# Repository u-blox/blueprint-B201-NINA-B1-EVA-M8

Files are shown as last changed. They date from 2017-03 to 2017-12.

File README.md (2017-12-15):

# blueprint-B201-NINA-B1-EVA-M8
This blueprint is a small solar powered location device with the NINA-B1 Bluetooth Low Energy and the EVA-M8 GNSS modules from u-blox.

* Provides a reference for integration of u-blox BLE and GNSS modules for location applications.
* Implements a low power solution integrating a harvesting power system.
* Gives an example of components choice, placement, and layout.

A demo firmware is available that can be used to test features of the blueprint. The firmware collects location data and provides this data via the standardized Bluetooth Low Energy GATT Location and Navigation Service.

## Disclaimer
Copyright (C) u-blox 

u-blox reserves all rights in this deliverable (documentation, software, etc.,
hereafter “Deliverable”). 

u-blox grants you the right to use, copy, modify and distribute the
Deliverable provided hereunder for any purpose without fee.

THIS DELIVERABLE IS BEING PROVIDED "AS IS", WITHOUT ANY EXPRESS OR IMPLIED
WARRANTY. IN PARTICULAR, NEITHER THE AUTHOR NOR U-BLOX MAKES ANY
REPRESENTATION OR WARRANTY OF ANY KIND CONCERNING THE MERCHANTABILITY OF THIS
DELIVERABLE OR ITS FITNESS FOR ANY PARTICULAR PURPOSE.

In case you provide us a feedback or make a contribution in the form of a
further development of the Deliverable (“Contribution”), u-blox will have the
same rights as granted to you, namely to use, copy, modify and distribute the
Contribution provided to us for any purpose without fee.

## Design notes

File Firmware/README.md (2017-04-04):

# B201 Location demo software

## General behavior

* Position, fix status, UTC time  and data valid are read from the NMEA message $xxRMC
* If fix status is ok and data are valid the position and time are presented in the standardized GATT Service ”Location and Navigation”
* If a remote device subscribes to GATT notifications these will be sent for every $xxRMC message NINA-B1 receives from the GNSS module
* When switching off the device with the ON/OFF button NINA-B1 will switch off the power to the GNSS module before entering sleep mode
* The device will automatically switch off if inactive for more than 3 min
* LED1 will indicate device running (0.2/1.8s) as well as any active BLE connection (0.4/4.0s)

## Program the device

Precompiled firmware is provided and can be used with B201 hardware. The .hex file is available in the ```/hex``` folder.   
**Please note!** This firmware requires SoftDevice s132_nrf52_3.0.0 to be programmed to the device.

## Compile the software

* Clone this repository   
```> git clone https://github.com/u-blox/blueprint-B201-NINA-B1-EVA-M8```

* Download the source code for nRF5 SDK version 12.2.0 from [Nordic](https://www.nordicsemi.com/eng/nordic/Products/nRF5-SDK/nRF5-SDK-v12-zip/54291)

* Copy ```custom_board.h``` to the ```/components/boards``` folder of the SDK

* Update the SDK_ROOT variable in the Makefile according to your installation of the nRF5 SDK   
```For example: SDK_ROOT := C:/nRF5_SDK_12.2.0```

* Go to the project directory (where the Makefile is located) and execute the ```make``` command

* The generated software (ninab1.hex) is located in the ```/_build``` folder

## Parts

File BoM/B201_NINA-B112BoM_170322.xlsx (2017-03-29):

Part Number | Part Reference | Quantity | Value | Description | Manufacturer | Manufacturer Part Number | Distributor | Distributor Part Number
TMP-143 | ANT2 | 1 | MWSL1203D | GPS Helix Antenna on SMA | Maruwa | MWSL1203D
TMP-112 | C1 C5 C8 C9 C13 C15 C16 C17 C19 C113 | 10 | 100n | MLCC0201 100nF 10V X5R 10% | TDK | C0603X5R1A104K030BC | Digi-Key | 445-7318-1-ND
TMP-165 | C6 C7 C10 C11 C12 | 5 | 10u | MLCC0805 10uF 10V X7R 10% | Murata | GRM21BR71A106KE51L | Digi-Key | 490-3905-6-ND
TMP-119 | C14 | 1 | 10n | MLCC0201 10nF 10V X7R 10% | TDK | C0603X7R1A103K030BA | Digi-Key | 445-6843-1-ND
TMP-113 | C18 | 1 | 1n | MLCC0201 1nF 25V X7R 10% | TDK | C0603X5R1E102K030BA | Digi-Key | 445-1790-1-ND
TMP-54 | C23 C24 | 2 | 1u | MLCC0603 1uF 16V X7R 10% | TDK | C1608X7R1C105K080AC | Digi-Key | 445-1604-2-ND
TMP-42 | D1 D4 D5 | 3 | LED Green | LED Green Clear 0603 SMD | Lite-On | LTST-C190KGKT | Digi-Key | 160-1435-6-ND
TMP-148 | FIL1 | 1 | B8813 | SAW Filter for GPS, COMPASS, GLONASS | TDK | B39162B8813P810 | Digikey | 495-7022-1-ND
TMP-132 | J1 | 1 | Header_2x5 | Header 2x5, p 1mm | Sullins | SFM210-LPSE-D05-SP-BK | Digi-Key | S9268-ND
TMP-137 | J2 | 1 | CP1454-A3-ST | Li-Ion battery 85mAh | Varta | CP1454-A3-ST | Weisbauer Elektronik
TMP-189 | J4 | 1 | SMA (F) edge | SMA (F) Jack for edge PCB mount, 1.6mm thickness | Samtec | SMA-J-P-H-ST-EM1 | Digi-Key | SAM8857-ND
TMP-139 | J9 | 1 | 0473460001 | micro USB conn SMT, RA | Molex | 0473460001 | Digi-Key | WM17141CT-ND
TMP-122 | L1 | 1 | 22u | Inductor 22uH 30% 450mohm, 360mA | Wurth | 744031220 | Digi-Key | 732-1012-2-ND
TMP-61 | L2 | 1 | 2u2 | Inductor 2,2uH 20% 110mohm, 1,2A | TDK | MLP2016H2R2MT0S1 | Digi-Key | 445-15724-1-ND
TMP-114 | L3 | 1 | 6n2 | Inductor 6,2nH +/-0.1nH 700mA | Murata | LQW15AN6N2B00D | Digi-Key | 490-6838-1-ND
TMP-149 | PCB1 | 1 | UBX-xxxxxx | NINA-B1, Blueprint B201 | u-blox | UBX-xxxxxx
TMP-130 | Q1 Q2 Q3 Q4 | 4 | CSD17381F4 | N-ch mosfet, 30V 3,1A | TI | CSD17381F4 | Digi-Key | 296-38913-1-ND
TMP-191 | R1 R2 | 2 | 18K | Thick-Film 18K 0201 1% | Rohm | MCR006YZPF1802 | Digi-Key | RHM18KABCT-ND
TMP-28 | R3 R58 | 2 | 470R | Thick-Film 470R 0402 5% | Rohm | MCR01MRTJ471 | Digi-Key | RHM470CECT-ND
TMP-134 | R4 | 1 | 330 | Thick-Film 330 0201 5% | Rohm | MCR006YRTJ331 | Digi-Key | RHM330CCCT-ND
TMP-135 | R5 R6 R12 R18 R59 | 5 | 100k | Thick-Film 100k 0201 1% | Rohm | MCR006YRTF1003 | Digi-Key | RHM100KCBCT-ND
TMP-133 | R7 R20 | 2 | 2K2 | Thick-Film 2K2 0201 1% | Rohm | MCR006YRTF2201 | Digi-Key | RHM2.2KCBCT-ND
TMP-123 | R8 R11 R16 | 3 | 5M49 | Thick-Film 5M49 0603 1% | Vishay | CRCW06035M49FKEA | Digi-Key | 541-5.49MHCT-ND
TMP-128 | R9 | 1 | 620k | Thick-Film 620k 0603 1% | Vishay | CRCW0603620KFKEA | Digi-Key | 541-620KHCT-ND
TMP-126 | R10 | 1 | 2M43 | Thick-Film 2M43 0603 1% | Vishay | CRCW06032M43FKEA | Digi-Key | 541-2.43MHCT-ND
TMP-127 | R13 R15 | 2 | 4M42 | Thick-Film 4M42 0603 1% | Vishay | CRCW06034M42FKEA | Digi-Key | 541-4.42MHCT-ND
TMP-125 | R14 | 1 | 9M31 | Thick-Film 9M31 0603 1% | Vishay | CRCW06039M31FKEA | Digi-Key | 541-9.31MHCT-ND
TMP-124 | R17 | 1 | 3M92 | Thick-Film 3M92 0603 1% | Vishay | CRCW06033M92FKEA | Digi-Key | 541-3.92MHCT-ND
TMP-141 | R19 | 1 | 10K | Thick-Film 10K 0201 1% | Rohm | MCR006YRTF1002 | Digi-Key | RHM10KCBCT-ND
TMP-190 | R21 | 1 | 820 | Thick-Film 820 0201 1% | Rohm | MCR006YRTF8200 | Digi-Key | RHM820CBCT-ND
TMP-144 | R54 R60 R63 R65 | 4 | 0R | Thick-Film 0R 0201 | Rohm | MCR006YRTJ000 | Digi-Key | RHM0.0CCCT-ND
TMP-156 | R61 | 1 | 2M | Thick-Film 2M 0402 1% | Samsung | RC1005F205CS | Digi-Key | 1276-4293-1-ND
TMP-155 | R62 | 1 | 3M | Thick-Film 3M 0402 1% | Samsung | RC1005F305CS | Digi-Key | 1276-4300-1-ND
TMP-136 | SW2 SW3 SW4 | 3 | B3U-1000P | Tactile Switch, Vertical | Omron | B3U-1000P | Digi-Key | SW1020CT-ND
TMP-150 | U1 | 1 | NINA-B112 | Stand-alone Bluetooth low energy module with internal antenna | u-blox | NINA-B112-00B-00
TMP-131 | U2 | 1 | BQ29700 | V-C protection for single cell Li-Ion/Li-Po | TI | BQ29700DSER | Digi-Key | 296-43985-1-ND
TMP-121 | U3 | 1 | SLMD121H04L | Monocristalline Solar cell 44,6mA@2V | IXYS | SLMD121H04L | Digi-Key | SLMD121H04L-ND
TMP-117 | U4 | 1 | LSM6DSL | always-on 3D accelerometer and gyroscope | ST micro | LSM6DSL | Digi-Key | 497-16705-1-ND
TMP-118 | U5 | 1 | BQ25504 | Ultra Low-Power Boost Conv. w/ Batt. Mgmt for Energy Harv. Appl. | TI | BQ25504RG | Digi-Key | 296-29741-1-ND
TMP-60 | U6 | 1 | TPS62740 | TPS6274x 360nA IQ Step Down Converter For Low Power Applications | TI | TPS62740DSST | Digi-Key | 296-37134-1-ND
TMP-108 | U7 | 1 | EVA-M8M | Concurrent GNSS module, GPS+GLONASS | u-blox | EVA-M8M-0
TMP-110 | U8 | 1 | BGA825L6S | Si-Ge LNA for GNSS | Infineon | BGA825L6S | Digi-Key | BGA 825L6S E6327CT-ND
TMP-109 | U9 | 1 | MX25U1635E | 16Mbit 1.8V CMOS Serial Flash Memory | Macronix | MX25U1635EZUI-10G | Digi-Key | 1092-1057-ND
TMP-140 | U10 | 1 | BQ25101 | Single Cell Li-Ion charger with 75nA Batt Leakage | TI | BQ25101YFPR | Digi-Key | 296-39933-1-ND
TMP-154 | U12 | 1 | LPV801 | Single Nanopower Operational Amplifier | TI | LPV801DBV | Digi-Key | PLPV801DBVT-ND
TMP-115 | Y1 | 1 | 32.768KHz | 32.768KHz crystal, 7pF Cl, -40/+85, 20ppm | ECS inc. | ECS-.327-7-12-TR | Digi-Key | XC1946CT-ND

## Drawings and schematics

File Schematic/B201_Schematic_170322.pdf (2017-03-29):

# 01 - Block Diagram

# Incl.:

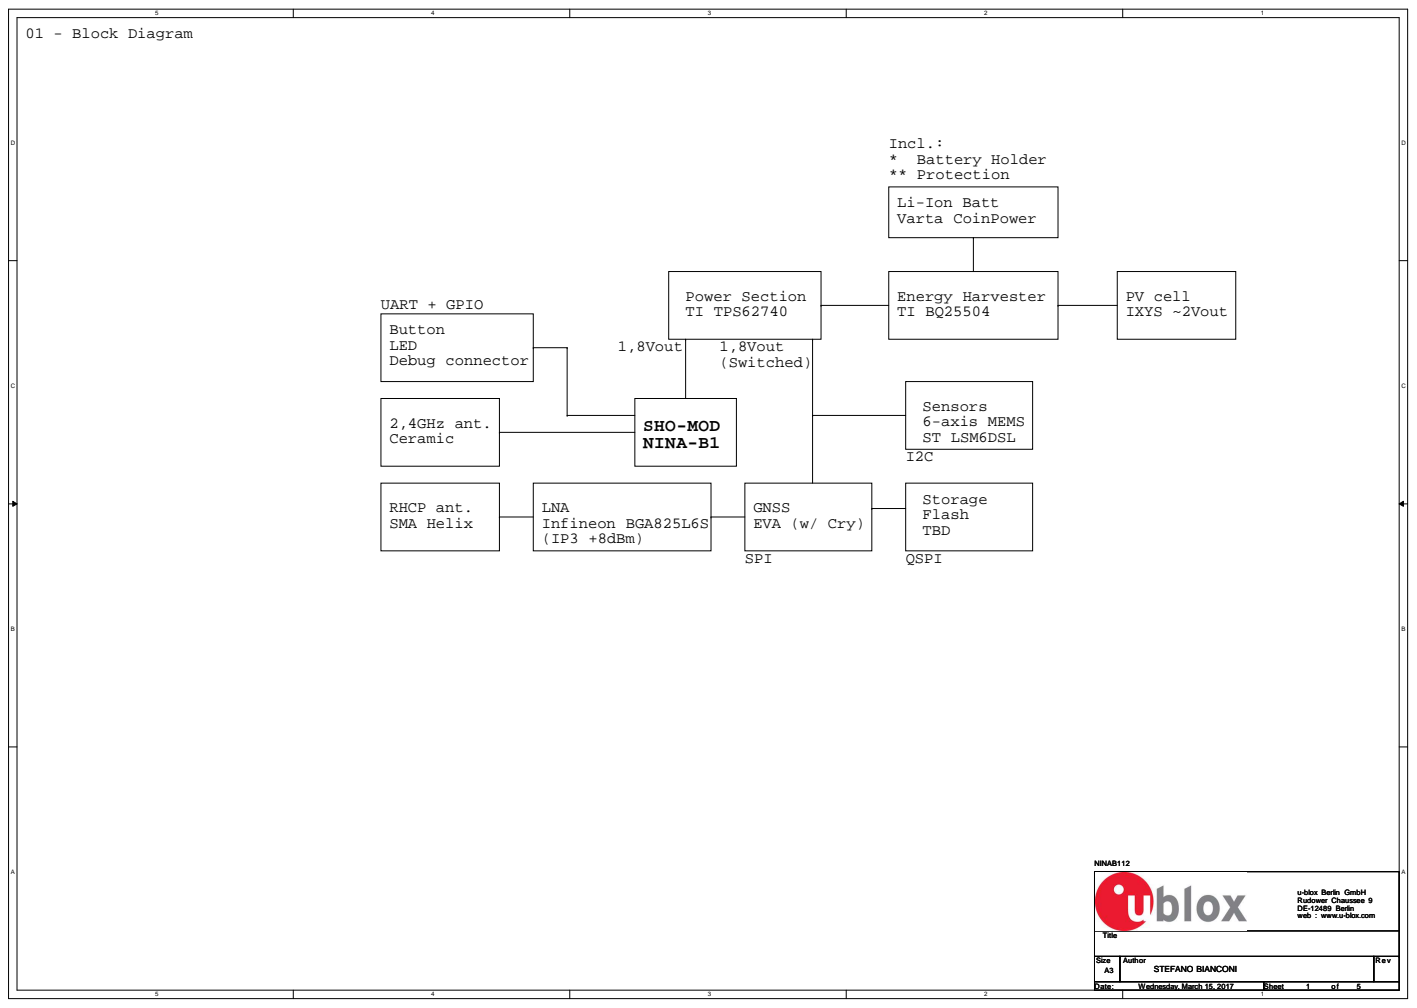
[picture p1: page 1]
PV cell IXYS ~2Vout; GNSS EVA (w/ Cry); Energy Harvester TI BQ25504; Power Section TI TPS62740; 1,8Vout; SHO-MOD NINA-B1; 1,8Vout (Switched); LNA Infineon BGA825L6S (IP3 +8dBm); RHCP ant. SMA Helix; 2,4GHz ant. Ceramic; Sensors 6-axis MEMS ST LSM6DSL; Storage Flash TBD; Button LED Debug connector; SPI; UART + GPIO; QSPI; Size; Title; Date:; Sheet; Author; STEFANO BIANCONI; Wednesday, March 15, 2017; NINAB112

* Battery Holder
** Protection
Li-Ion Batt
Varta CoinPower

u-blox Berlin GmbH
Rudower Chaussee 9
DE-12489 Berlin
web : www.u-blox.com

# Revision History

Date | Reason to Change | Description

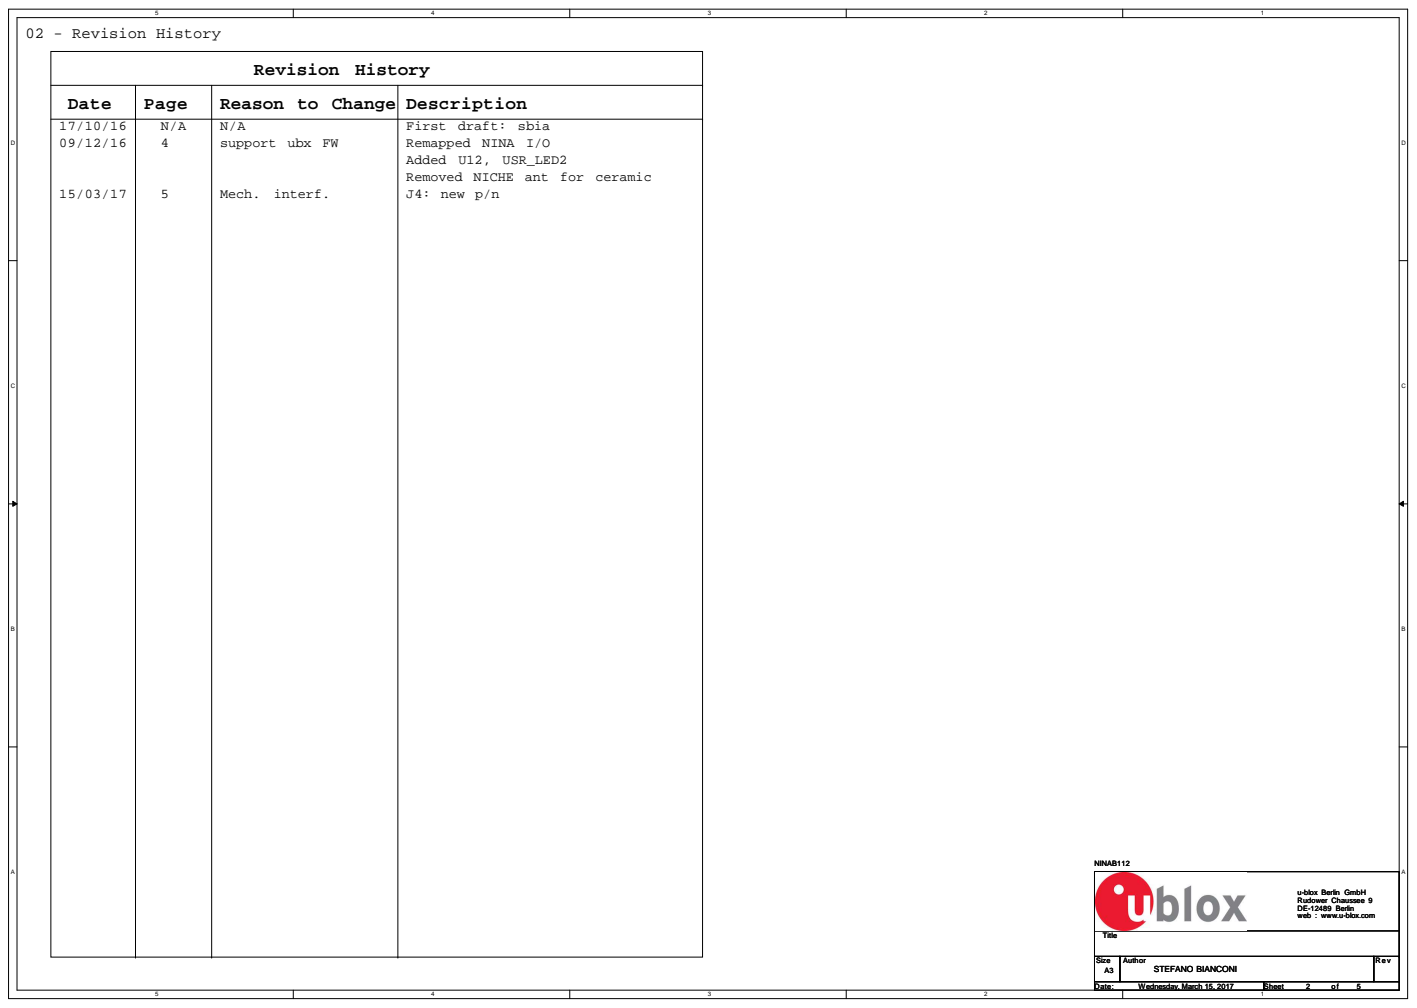
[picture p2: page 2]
Page; First draft: sbia; 02 - Revision History; support ubx FW; Remapped NINA I/O; Mech. interf.; J4: new p/n; Size; Title; Date:; Sheet; Author; STEFANO BIANCONI; Wednesday, March 15, 2017; NINAB112

Added U12, USR_LED2
Removed NICHE ant for ceramic

u-blox Berlin GmbH
Rudower Chaussee 9
DE-12489 Berlin
web : www.u-blox.com

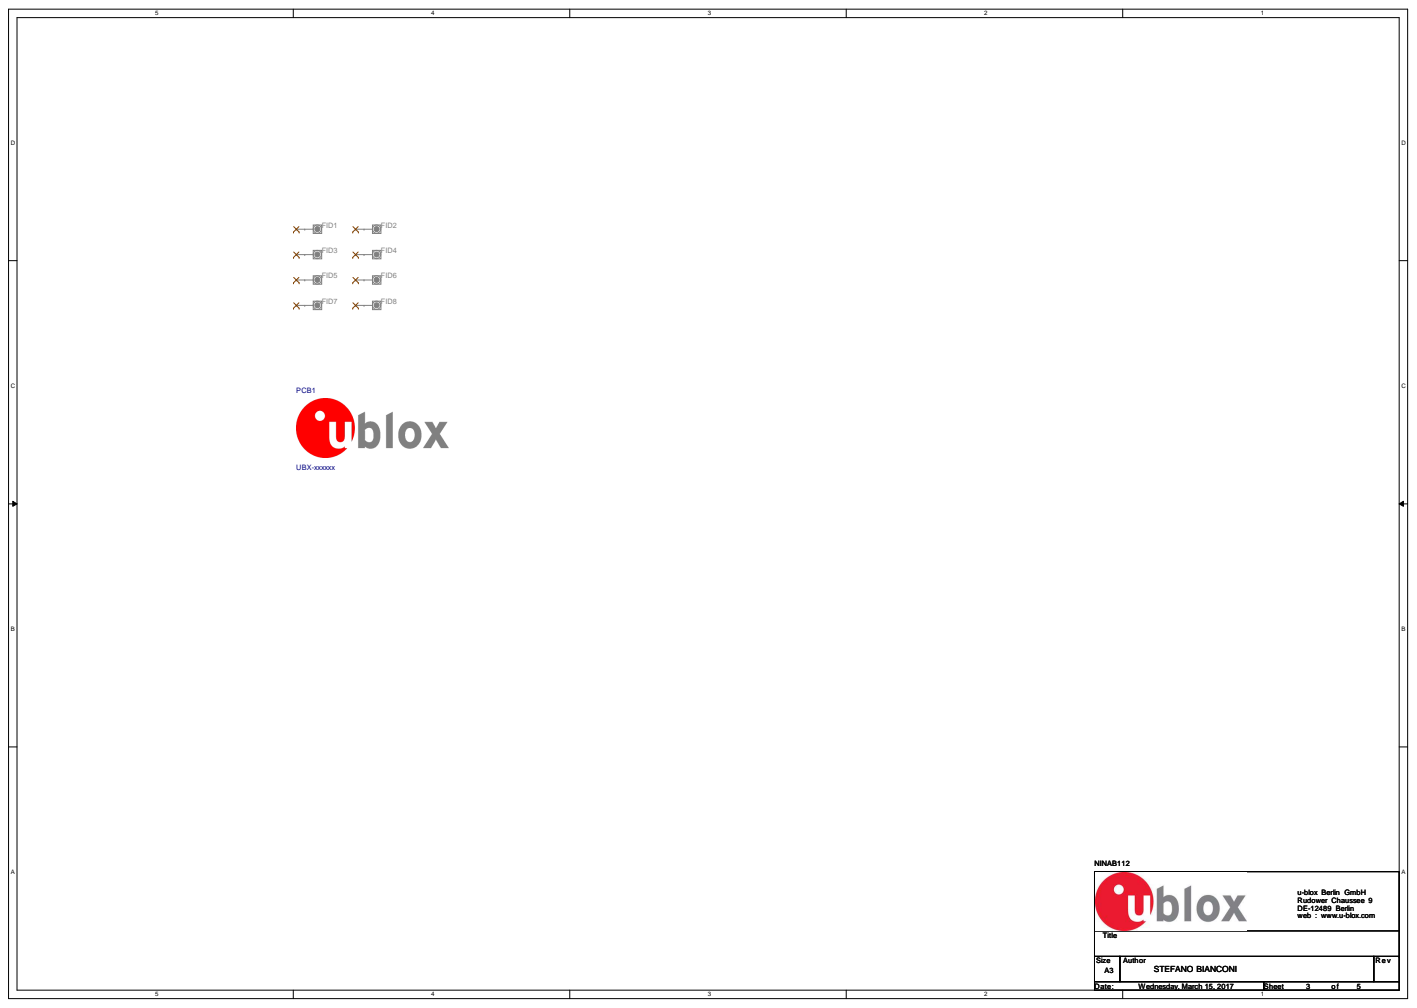
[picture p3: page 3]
Size; Title; Date:; Sheet; Author; STEFANO BIANCONI; Wednesday, March 15, 2017; NINAB112; FID1; FID3; FID5; FID7; FID2; FID4; PCB1; UBX-xxxxxx; FID6; FID8

u-blox Berlin GmbH
Rudower Chaussee 9
DE-12489 Berlin
web : www.u-blox.com

# Backup Charger

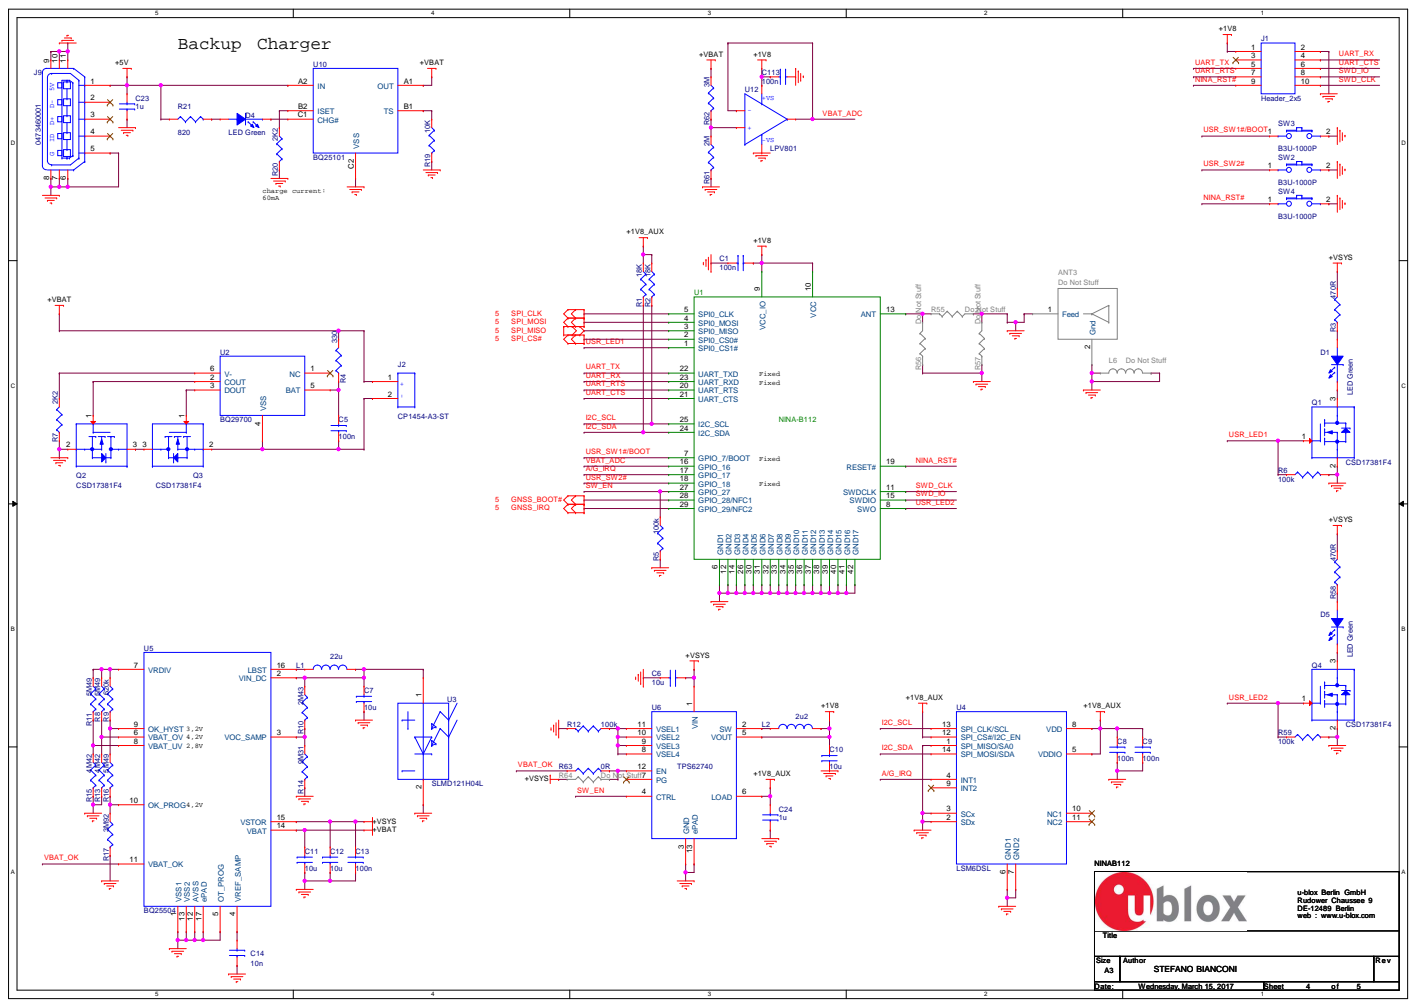
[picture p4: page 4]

u-blox Berlin GmbH
Rudower Chaussee 9
DE-12489 Berlin
web : www.u-blox.com

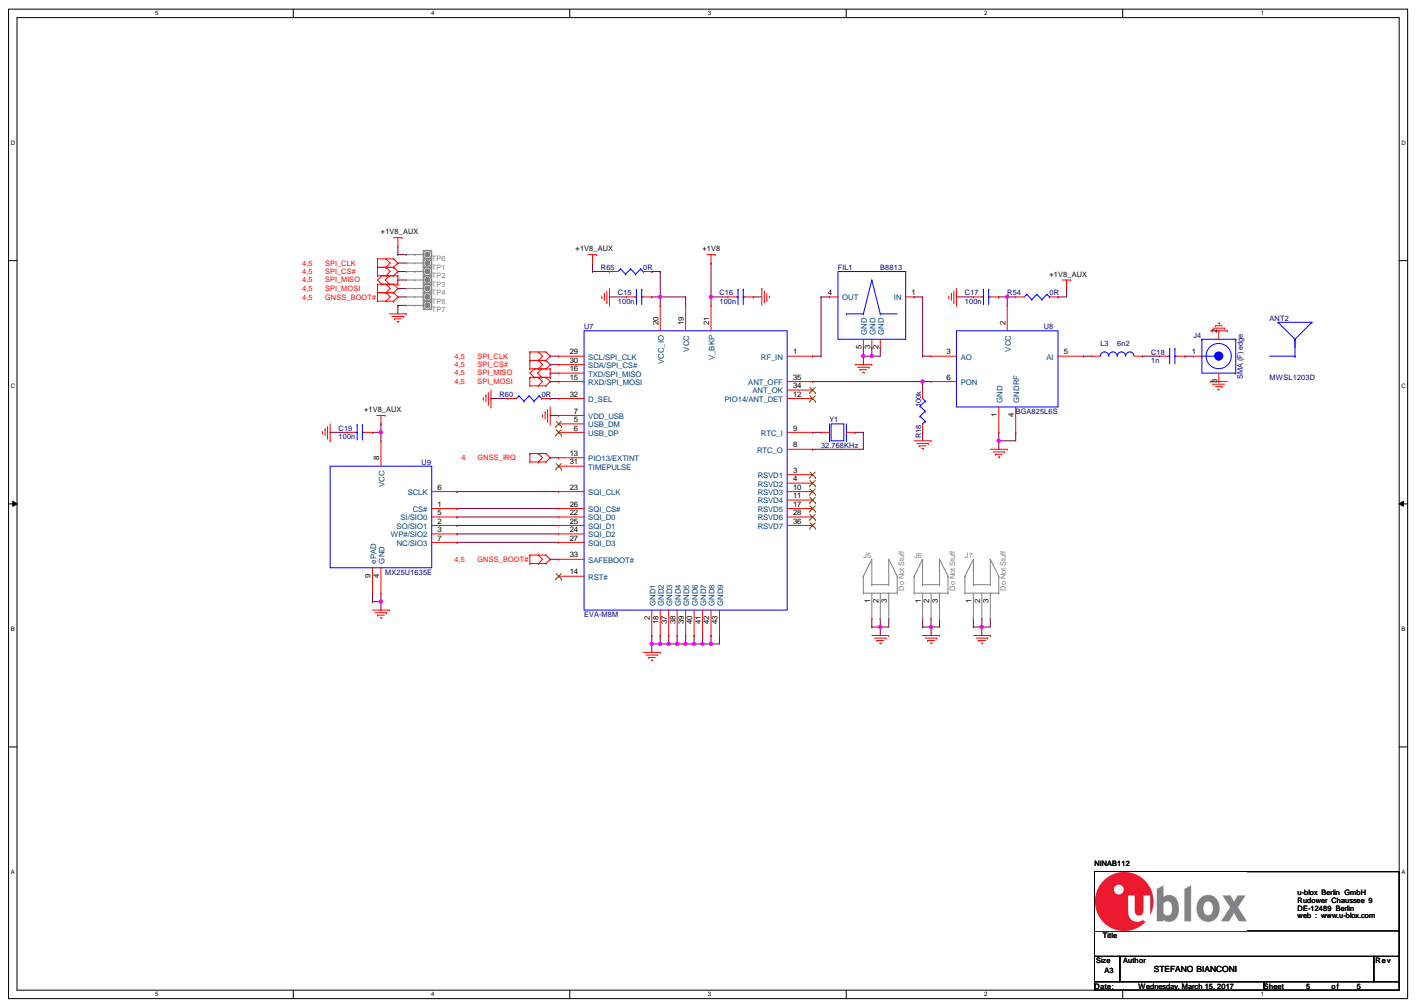
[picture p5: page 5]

u-blox Berlin GmbH
Rudower Chaussee 9
DE-12489 Berlin
web : www.u-blox.com

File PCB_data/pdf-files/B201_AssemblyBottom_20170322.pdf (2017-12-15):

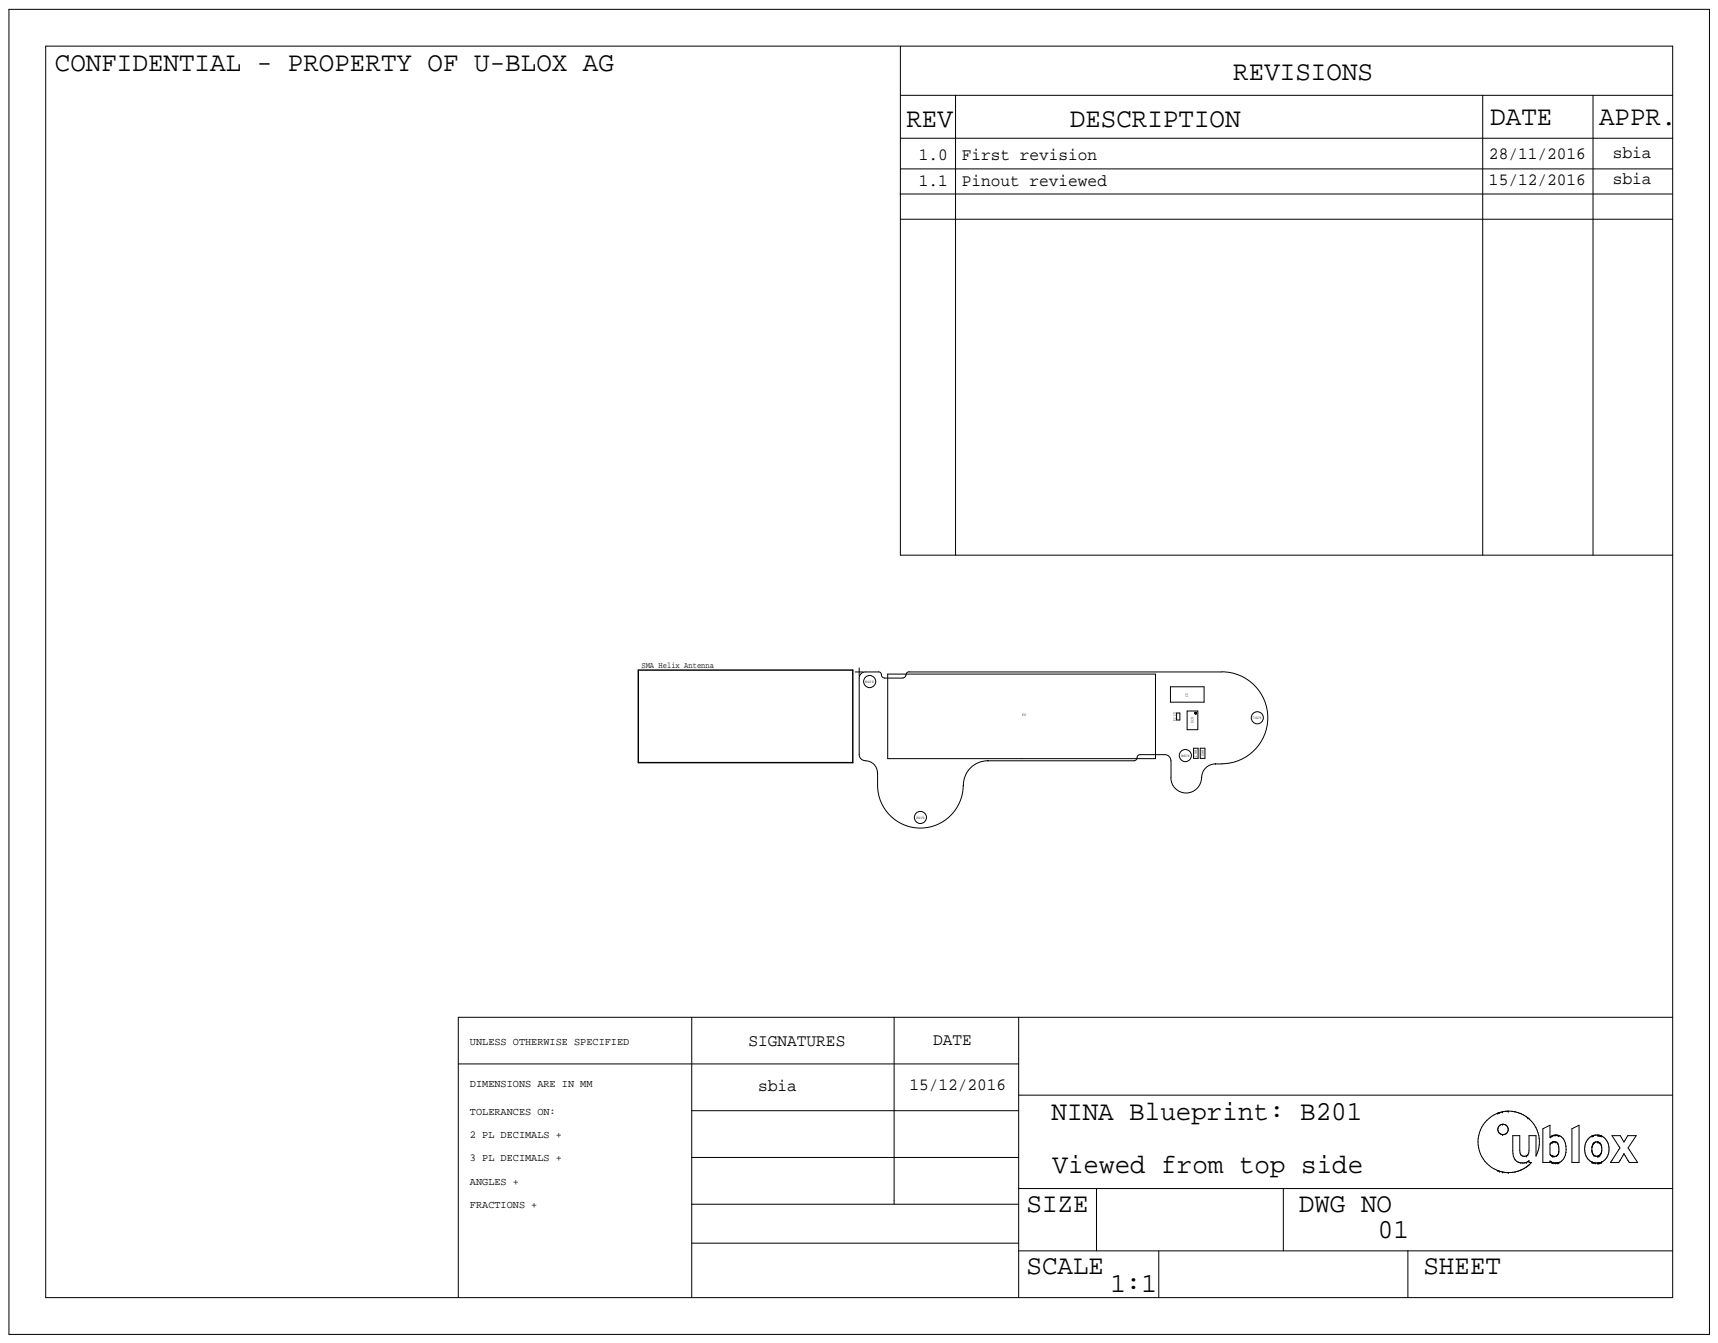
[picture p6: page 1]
R61FID6

CONFIDENTIAL - PROPERTY OF U-BLOX AG

REVISIONS

REV | DESCRIPTION | DATE | APPR.

1.0 | First revision | 28/11/2016 | sbia
1.1 | Pinout reviewed | 15/12/2016 | sbia

SMA Helix Antenna

UNLESS OTHERWISE SPECIFIED | SIGNATURES | DATE

DIMENSIONS ARE IN MM TOLERANCES ON: 2 PL DECIMALS + 3 PL DECIMALS + ANGLES + FRACTIONS + | sbia | 15/12/2016

NINA Blueprint: B201 Viewed from top side

SIZE | DWG NO 01

SCALE 1:1 | SHEET

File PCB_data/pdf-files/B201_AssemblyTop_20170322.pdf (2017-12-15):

# CONFIDENTIAL - PROPERTY OF U-BLOX AG

| REVISIONS

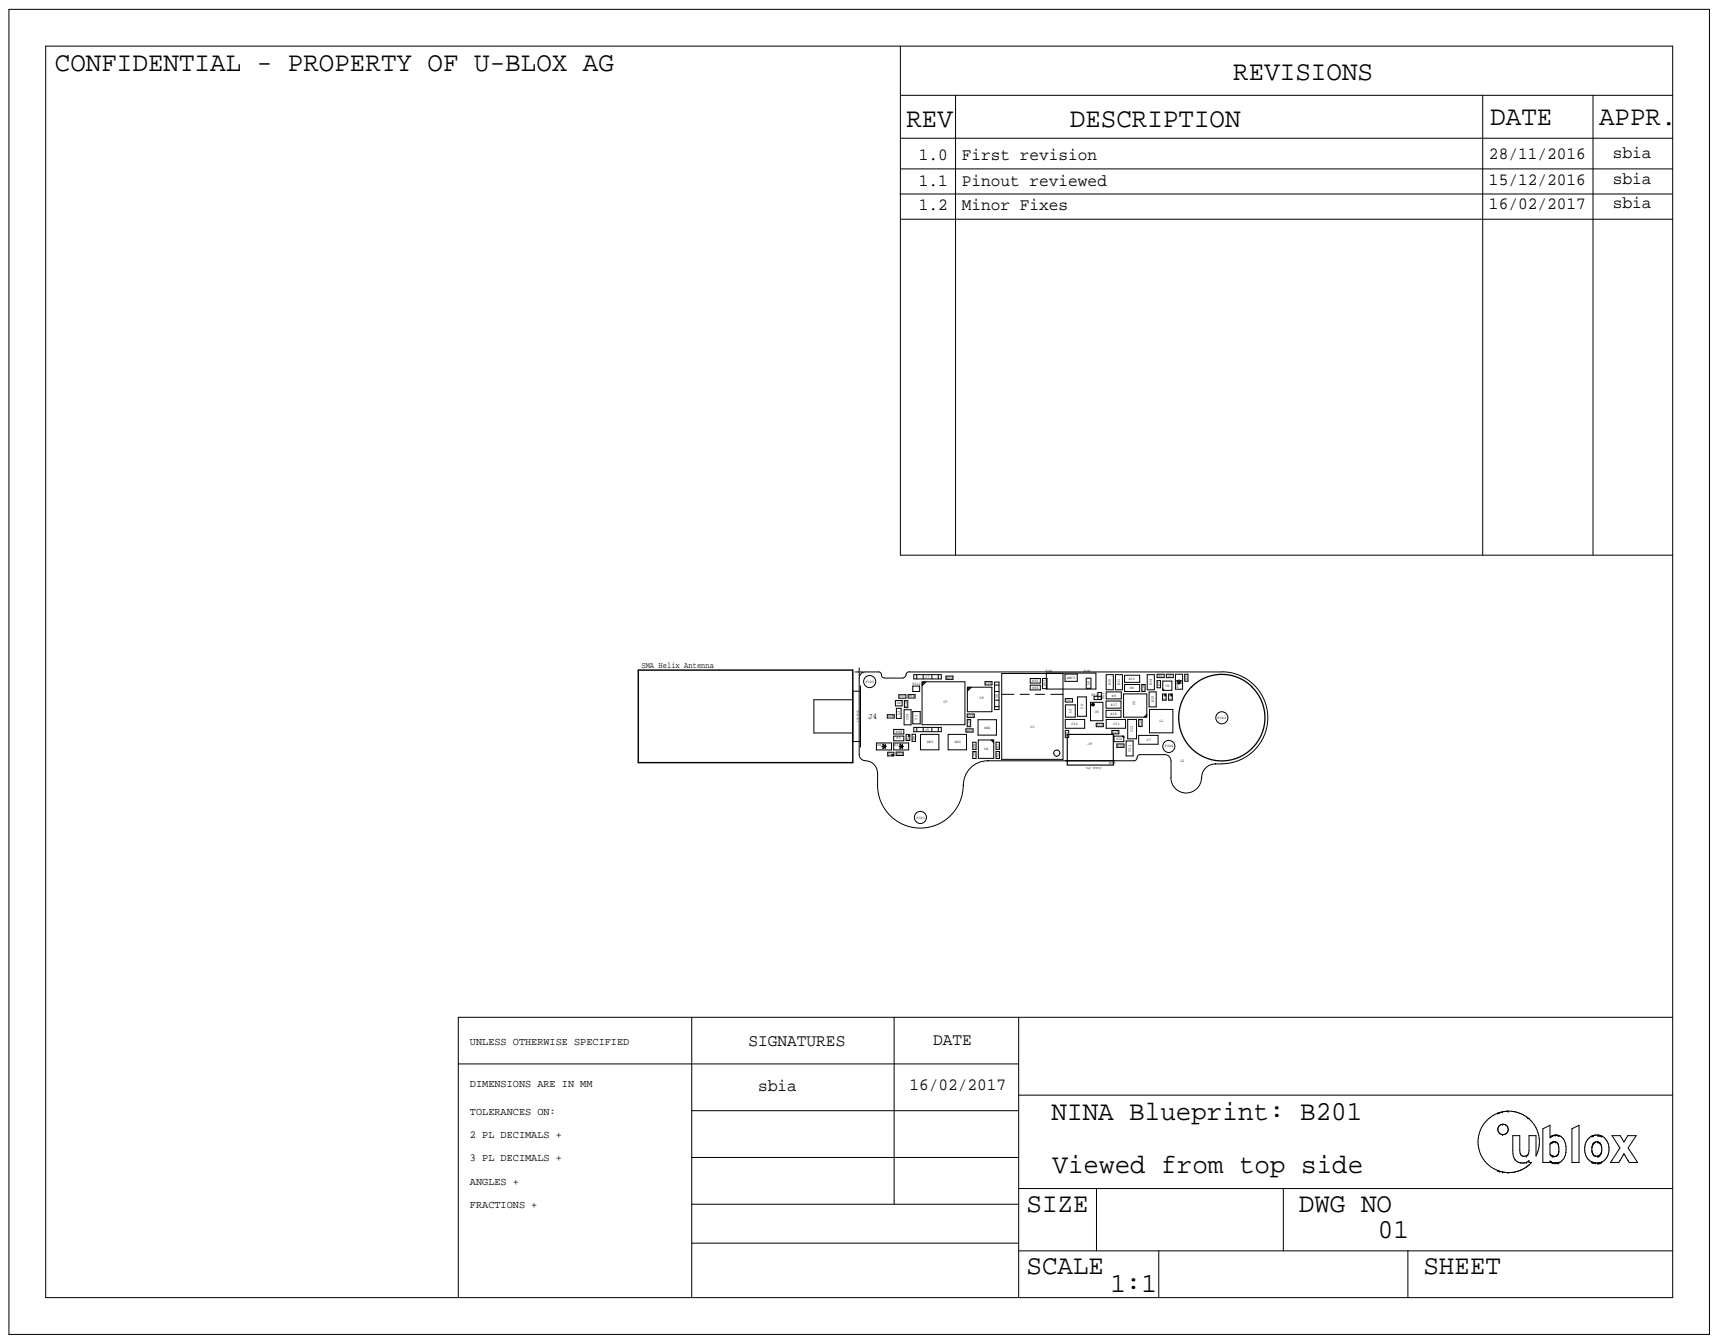
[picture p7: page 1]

REV | DESCRIPTION | DATE | APPR.

1.0 | First revision | 28/11/2016 | sbia
1.1 | Pinout reviewed | 15/12/2016 | sbia
1.2 | Minor Fixes | 16/02/2017 | sbia

UNLESS OTHERWISE SPECIFIED | SIGNATURES | DATE

DIMENSIONS ARE IN MM TOLERANCES ON: 2 PL DECIMALS + 3 PL DECIMALS + ANGLES + FRACTIONS + | sbia | 16/02/2017

NINA Blueprint: B201 Viewed from top side

SIZE | DWG NO 01

SCALE 1:1 | SHEET

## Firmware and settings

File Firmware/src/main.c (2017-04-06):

/*
 * Copyright (C) u-blox 
 * 
 * u-blox reserves all rights in this deliverable (documentation, software, etc.,
 * hereafter “Deliverable”). 
 * 
 * u-blox grants you the right to use, copy, modify and distribute the
 * Deliverable provided hereunder for any purpose without fee.
 * 
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
 * In case you provide us a feedback or make a contribution in the form of a
 * further development of the Deliverable (“Contribution”), u-blox will have the
 * same rights as granted to you, namely to use, copy, modify and distribute the
 * Contribution provided to us for any purpose without fee.
 */

/**@brief B201 Location demo application main file.
 *
 * This file contains the source code for the B201 Location demo application using the Location and Navigation service
 * (and also Device Information services).
 */

#include <stdint.h>
#include <string.h>
#include "nordic_common.h"
#include "nrf.h"
#include "nrf_assert.h"
#include "nrf_error.h"
#include "ble.h"
#include "ble_hci.h"
#include "ble_srv_common.h"
#include "ble_advdata.h"
#include "ble_advertising.h"
#include "ble_lns.h"
#include "ble_dis.h"
#include "sensorsim.h"
#include "app_timer.h"
#include "softdevice_handler.h"
#include "ble_conn_params.h"
#include "bsp.h"
#include "bsp_btn_ble.h"
#include "peer_manager.h"
#include "fds.h"
#include "fstorage.h"
#include "ble_conn_state.h"
#define NRF_LOG_MODULE_NAME "APP"
#include "nrf_log.h"
#include "nrf_log_ctrl.h"
#include "nrf_drv_spi.h"
#include "nrf_delay.h"


#define IS_SRVC_CHANGED_CHARACT_PRESENT      1                                               /**< Include or not the service_changed characteristic. If not enabled, the server's database cannot be changed for the lifetime of the device. */

#if (NRF_SD_BLE_API_VERSION == 3)
#define NRF_BLE_MAX_MTU_SIZE                 GATT_MTU_SIZE_DEFAULT                           /**< MTU size used in the softdevice enabling and to reply to a BLE_GATTS_EVT_EXCHANGE_MTU_REQUEST event. */
#endif

#define APP_FEATURE_NOT_SUPPORTED            BLE_GATT_STATUS_ATTERR_APP_BEGIN + 2            /**< Reply when unsupported features are requested. */

#define CENTRAL_LINK_COUNT                   0                                               /**< Number of central links used by the application. When changing this number remember to adjust the RAM settings*/
#define PERIPHERAL_LINK_COUNT                1                                               /**< Number of peripheral links used by the application. When changing this number remember to adjust the RAM settings*/

#define DEVICE_NAME_PREFIX                   "B201-"                                         /**< Name prefix, 4 chars from the MAC will be added as well. */
#define MANUFACTURER_NAME                    "u-blox"                                        /**< Manufacturer. Will be passed to Device Information Service. */
#define MODEL_NUMBER                         "B201"                                          /**< Model number. Will be passed to Device Information Service. */
#define SW_VERSION                           "0.1.4"                                         /**< Software version. Will be passed to Device Information Service. */
#define APP_ADV_INTERVAL                     40                                              /**< The advertising interval (in units of 0.625 ms; this value corresponds to 25 ms). */
#define APP_ADV_TIMEOUT_IN_SECONDS           180                                             /**< The advertising time-out in units of seconds. */

#define APP_TIMER_PRESCALER                  0                                               /**< Value of the RTC1 PRESCALER register. */
#define APP_TIMER_OP_QUEUE_SIZE              4                                               /**< Size of timer operation queues. */

#define LOC_AND_NAV_DATA_INTERVAL            APP_TIMER_TICKS(1000, APP_TIMER_PRESCALER)      /**< Location and Navigation data interval (ticks). */
#define SPI_READ_INTERVAL                    APP_TIMER_TICKS(10, APP_TIMER_PRESCALER)        /**< SPI read interval (ticks). */

#define SECOND_10_MS_UNITS                   100                                             /**< Definition of 1 second, when 1 unit is 10 ms. */
#define MIN_CONN_INTERVAL                    MSEC_TO_UNITS(20, UNIT_1_25_MS)                 /**< Minimum connection interval (100 ms). */
#define MAX_CONN_INTERVAL                    MSEC_TO_UNITS(40, UNIT_1_25_MS)                 /**< Maximum connection interval (250 ms). */
#define SLAVE_LATENCY                        0                                               /**< Slave latency. */
#define CONN_SUP_TIMEOUT                     (4 * SECOND_10_MS_UNITS)                        /**< Connection supervisory time-out (4 seconds). Supervision time-out uses 10 ms units. */

#define FIRST_CONN_PARAMS_UPDATE_DELAY       APP_TIMER_TICKS(5000, APP_TIMER_PRESCALER)      /**< Time from initiating event (connect or start of notification) to first time sd_ble_gap_conn_param_update is called (5 seconds). */
#define NEXT_CONN_PARAMS_UPDATE_DELAY        APP_TIMER_TICKS(30000, APP_TIMER_PRESCALER)     /**< Time between each call to sd_ble_gap_conn_param_update after the first (30 seconds). */
#define MAX_CONN_PARAMS_UPDATE_COUNT         3                                               /**< Number of attempts before giving up the connection parameter negotiation. */

#define SEC_PARAM_BOND                       1                                               /**< Perform bonding. */
#define SEC_PARAM_MITM                       0                                               /**< Man In The Middle protection not required. */
#define SEC_PARAM_LESC                       0                                               /**< LE Secure Connections not enabled. */
#define SEC_PARAM_KEYPRESS                   0                                               /**< Keypress notifications not enabled. */
#define SEC_PARAM_IO_CAPABILITIES            BLE_GAP_IO_CAPS_NONE                            /**< No I/O capabilities. */
#define SEC_PARAM_OOB                        0                                               /**< Out Of Band data not available. */
#define SEC_PARAM_MIN_KEY_SIZE               7                                               /**< Minimum encryption key size. */
#define SEC_PARAM_MAX_KEY_SIZE               16                                              /**< Maximum encryption key size. */

#define DEAD_BEEF                            0xDEADBEEF                                      /**< Value used as error code on stack dump, can be used to identify stack location on stack unwind. */

#define SPI_INSTANCE                         0                                               /**< SPI instance index. */


static const nrf_drv_spi_t                   spi = NRF_DRV_SPI_INSTANCE(SPI_INSTANCE);       /**< SPI instance. */
static uint8_t                               m_rx_buf[1];                                    /**< SPI RX buffer. */
static const uint8_t                         m_length = sizeof(m_rx_buf);                    /**< SPI RX buffer length. */
static uint8_t                               m_gnss_buffer[256];                             /**< GNSS RX buffer. */
static uint8_t                               m_gnss_index = 0;                               /**< GNSS buffer index. */
static bool                                  m_awaiting_new_message = true;                  /**< Awaiting new GNSS message flag. */
static bool                                  m_location_speed_data_valid = false;            /**< Flag indicating if received gnss data are valid. */
static bool                                  m_gnss_fix = false;                             /**< GNSS Fix. */

static char                                  m_device_name[16];

static uint16_t                              m_conn_handle = BLE_CONN_HANDLE_INVALID;        /**< Handle of the current connection. */
static ble_lns_t                             m_lns;                                          /**< Structure used to identify the location and navigation service. */

APP_TIMER_DEF(m_loc_and_nav_timer_id);                                                       /**< Location and navigation measurement timer. */
APP_TIMER_DEF(m_spi_timer_id);                                                               /**< SPI read timer. */

static ble_lns_loc_speed_t                   m_location_speed;                               /**< Location and speed data. */
static ble_lns_loc_speed_t                   m_last_read_location_speed;                     /**< Last location and speed data read from the  */

static ble_uuid_t                            m_adv_uuids[] = {
                                                               {BLE_UUID_LOCATION_AND_NAVIGATION_SERVICE,  BLE_UUID_TYPE_BLE},
                                                               {BLE_UUID_DEVICE_INFORMATION_SERVICE,       BLE_UUID_TYPE_BLE}
                                                             };

static const ble_lns_loc_speed_t initial_lns_location_speed = {
    .instant_speed_present   = false,
    .total_distance_present  = false,
    .location_present        = true,
    .elevation_present       = false,
    .heading_present         = false,
    .rolling_time_present    = false,
    .utc_time_time_present   = true,
    .position_status         = BLE_LNS_NO_POSITION,
    .data_format             = BLE_LNS_SPEED_DISTANCE_FORMAT_2D,
    .elevation_source        = BLE_LNS_ELEV_SOURCE_POSITIONING_SYSTEM,
    .heading_source          = BLE_LNS_HEADING_SOURCE_COMPASS,
    .latitude                = 0,
    .longitude               = 0,
    .utc_time                = {
                                 .year    = 2017,
                                 .month   = 1,
                                 .day     = 1,
                                 .hours   = 12,
                                 .minutes = 0,
                                 .seconds = 0
                               }
};

static void advertising_start(void);


/**@brief hex to int.
 *
 * @details This function will convert a character hex to int.
 *
 * @param[in] ch  A character in hex.
 *
 * @return  The integer of the hexadecimal character.
 */
uint8_t character_hex_to_int(uint8_t ch) 
{
  if (ch >= 'A' && ch <= 'F')
    return ch - 'A' + 10;
  else if (ch >= 'a' && ch <= 'f')
    return ch - 'a' + 10;
  else
    return ch - '0';
}


/**@brief Process a GNRMC message.
 */
void process_GNRMC_message(void)
{
    uint8_t message_index, field, field_index;
    int32_t latitude = 0;  //Unit is in degrees with a resolution of 1/(10^7)
    int32_t longitude = 0; //Unit is in degrees with a resolution of 1/(10^7)
    uint8_t status = ' ';
    uint8_t north_south = ' ';
    uint8_t east_west = ' ';
    uint8_t pos_mode = ' ';
    
    //$xxRMC,time,status,lat,NS,long,EW,spd,cog,date,mv,mvEW,posMode,navStatus*cs<CR><LF>
    //example: $GPRMC,083559.00,A,4717.11437,N,00833.91522,E,0.004,77.52,091202,,,A,V*57
    
    for (message_index=0,field=0,field_index=0; (message_index < m_gnss_index) && (field <= 13); message_index++)
    {
        if (m_gnss_buffer[message_index] == ',' || m_gnss_buffer[message_index] == '*')
        {
            field++;
            field_index = 0;
        }
        else
        {
            switch (field) {
                
                case 1: //Time
                    //Hour
                    if (field_index == 0)
                        m_last_read_location_speed.utc_time.hours = 10*character_hex_to_int(m_gnss_buffer[message_index]);
                    if (field_index == 1)
                        m_last_read_location_speed.utc_time.hours += character_hex_to_int(m_gnss_buffer[message_index]);
                    //Minute
                    if (field_index == 2)
                        m_last_read_location_speed.utc_time.minutes = 10*character_hex_to_int(m_gnss_buffer[message_index]);
                    if (field_index == 3)
                        m_last_read_location_speed.utc_time.minutes += character_hex_to_int(m_gnss_buffer[message_index]);
                    //Second
                    if (field_index == 4)
                        m_last_read_location_speed.utc_time.seconds = 10*character_hex_to_int(m_gnss_buffer[message_index]);
                    if (field_index == 5)
                        m_last_read_location_speed.utc_time.seconds += character_hex_to_int(m_gnss_buffer[message_index]);                    
                    break;
                    
                case 2: //Status
                    status = m_gnss_buffer[message_index];
                    break;
                    
                case 3: //Latitude
                    if (field_index == 0)
                        latitude = 10000000*10*character_hex_to_int(m_gnss_buffer[message_index]);
                    if (field_index == 1)
                        latitude += 10000000*character_hex_to_int(m_gnss_buffer[message_index]);
                    if (field_index == 2)
                        latitude += (10000000*10*character_hex_to_int(m_gnss_buffer[message_index]))/60;
                    if (field_index == 3)
                        latitude += (10000000*character_hex_to_int(m_gnss_buffer[message_index]))/60;
                    //field_index == 4 => '.' -> do nothing
                    if (field_index == 5)
                        latitude += (10000000/10*character_hex_to_int(m_gnss_buffer[message_index]))/60;
                    if (field_index == 6)
                        latitude += (10000000/100*character_hex_to_int(m_gnss_buffer[message_index]))/60;
                    if (field_index == 7)
                        latitude += (10000000/1000*character_hex_to_int(m_gnss_buffer[message_index]))/60;
                    if (field_index == 8)
                        latitude += (10000000/10000*character_hex_to_int(m_gnss_buffer[message_index]))/60;
                    if (field_index == 9)
                        latitude += (10000000/100000*character_hex_to_int(m_gnss_buffer[message_index]))/60;
                    break;
                    
                case 4: //North/South
                    north_south = m_gnss_buffer[message_index];
                    break;
                    
                case 5: //Longitude
                    if (field_index == 0)
                        longitude = 10000000*100*character_hex_to_int(m_gnss_buffer[message_index]);
                    if (field_index == 1)
                        longitude += 10000000*10*character_hex_to_int(m_gnss_buffer[message_index]);
                    if (field_index == 2)
                        longitude += 10000000*character_hex_to_int(m_gnss_buffer[message_index]);
                    if (field_index == 3)
                        longitude += (10000000*10*character_hex_to_int(m_gnss_buffer[message_index]))/60;
                    if (field_index == 4)
                        longitude += (10000000*character_hex_to_int(m_gnss_buffer[message_index]))/60;
                    //field_index == 5 => '.' -> do nothing
                    if (field_index == 6)
                        longitude += (10000000/10*character_hex_to_int(m_gnss_buffer[message_index]))/60;
                    if (field_index == 7)
                        longitude += (10000000/100*character_hex_to_int(m_gnss_buffer[message_index]))/60;
                    if (field_index == 8)
                        longitude += (10000000/1000*character_hex_to_int(m_gnss_buffer[message_index]))/60;
                    if (field_index == 9)
                        longitude += (10000000/10000*character_hex_to_int(m_gnss_buffer[message_index]))/60;
                    if (field_index == 10)
                        longitude += (10000000/100000*character_hex_to_int(m_gnss_buffer[message_index]))/60;
                    break;
                    
                case 6: //East/West
                    east_west = m_gnss_buffer[message_index];
                    break;
                    
                case 9: //Date
                    //Day
                    if (field_index == 0)
                        m_last_read_location_speed.utc_time.day = 10*character_hex_to_int(m_gnss_buffer[message_index]);
                    if (field_index == 1)
                        m_last_read_location_speed.utc_time.day += character_hex_to_int(m_gnss_buffer[message_index]);
                    //Month
                    if (field_index == 2)
                        m_last_read_location_speed.utc_time.month = 10*character_hex_to_int(m_gnss_buffer[message_index]);
                    if (field_index == 3)
                        m_last_read_location_speed.utc_time.month += character_hex_to_int(m_gnss_buffer[message_index]);
                    //Year
                    if (field_index == 4)
                        m_last_read_location_speed.utc_time.year = 10*character_hex_to_int(m_gnss_buffer[message_index]);
                    if (field_index == 5)
                        m_last_read_location_speed.utc_time.year += character_hex_to_int(m_gnss_buffer[message_index]);                        
                    break;
                    
                case 12: //posMode
                    pos_mode = m_gnss_buffer[message_index];
                    NRF_LOG_RAW_INFO("posMode\r\n");
                    break;
                    
                default:
                    break;
            }
            field_index++;
        }
    }

    //Data valid
    if (status == 'A')
        m_location_speed_data_valid = true;
    else
        m_location_speed_data_valid = false;

    //GNSS Fix
    if (pos_mode == 'A' || pos_mode == 'D' || pos_mode == 'E' || pos_mode == 'F' || pos_mode == 'R')
        m_gnss_fix = true;
    else
        m_gnss_fix = false;
    
    //Adjust latitude regarding North/South
    if (north_south == 'N')
        m_last_read_location_speed.latitude = latitude;
    else if (north_south == 'S')
        m_last_read_location_speed.latitude = -latitude;
    else 
        m_last_read_location_speed.latitude = 0;

    //Adjust longitude regarding East/West
    if (east_west == 'E')
        m_last_read_location_speed.longitude = longitude;
    else if (east_west == 'W')
        m_last_read_location_speed.longitude = -longitude;
    else 
        m_last_read_location_speed.longitude = 0;
   
    /* Debug */
    NRF_LOG_RAW_INFO("%s\r\n",(uint32_t)m_gnss_buffer);
    NRF_LOG_RAW_INFO("Time: %02d:%02d:%02d\r\n",m_last_read_location_speed.utc_time.hours, 
                     m_last_read_location_speed.utc_time.minutes,m_last_read_location_speed.utc_time.seconds);
    NRF_LOG_RAW_INFO("Date: %02d-%02d-%02d\r\n",m_last_read_location_speed.utc_time.year, 
                     m_last_read_location_speed.utc_time.month,m_last_read_location_speed.utc_time.day);                     
    NRF_LOG_RAW_INFO("Status: %c\r\n",status);
    NRF_LOG_RAW_INFO("pos_mode: %c\r\n",pos_mode);
    NRF_LOG_RAW_INFO("Lat:  %d deg\r\n",m_last_read_location_speed.latitude);
    NRF_LOG_RAW_INFO("Long: %d deg\r\n",m_last_read_location_speed.longitude);
}


/**@brief Process a nmea message.
 */
void process_nmea_message(void)
{
    if ((m_gnss_buffer[1] == 'G') &&
        (m_gnss_buffer[2] == 'N') &&
        (m_gnss_buffer[3] == 'R') && 
        (m_gnss_buffer[4] == 'M') && 
        (m_gnss_buffer[5] == 'C'))
    {
        process_GNRMC_message();
    }

    //NRF_LOG_RAW_INFO("%s",(uint32_t)m_gnss_buffer);
}


/**@brief Function for handling events from the SPI module.
 */
void spi_event_handler(nrf_drv_spi_evt_t const * p_event)
{
    if (m_awaiting_new_message == true)
    {
        if (m_rx_buf[0] == '$')
        {
            m_awaiting_new_message = false;
            memset(m_gnss_buffer, 0, sizeof(m_gnss_buffer));
            m_gnss_index = 0;
        }        
    }
    if (m_awaiting_new_message == false)
    {
        if (m_gnss_index >= 255)
        {
            m_awaiting_new_message = true;
        }
        else if (m_rx_buf[0] == '\n')
        {
            process_nmea_message();
            m_awaiting_new_message = true;            
        }
        else
        {
            m_gnss_buffer[m_gnss_index++] = m_rx_buf[0];
        }
    }
}


/**@brief SPI time-out handler.
 *
 * @details This function will be called each time the SPI timer expires.
 *
 * @param[in]   p_context   Pointer used for passing some arbitrary information (context) from the
 *                          app_start_timer() call to the time-out handler.
 */
 static void spi_timeout_handler(void * p_context)
{    
    //Reset rx buffer
    memset(m_rx_buf, 0, m_length);

    //Read SPI
    APP_ERROR_CHECK(nrf_drv_spi_transfer(&spi, NULL, 0, m_rx_buf, m_length));
}
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
int main(void)
{
    uint32_t err_code;
    bool erase_bonds;

    err_code = NRF_LOG_INIT(NULL);
    APP_ERROR_CHECK(err_code);

    // Initialize
    timers_init();
    buttons_leds_init(&erase_bonds);

    ble_stack_init();
    peer_manager_init(erase_bonds);
    if (erase_bonds == true)
    {
        NRF_LOG_INFO("Bonds erased!\r\n");
    }
    gap_params_init();
    advertising_init();
    services_init();
    conn_params_init();
    spi_init();
    gnss_accel_power_init();    
    
    // Start execution
    application_timers_start();
    NRF_LOG_INFO("Location and Navigation App started\r\n");
    err_code = ble_advertising_start(BLE_ADV_MODE_FAST);
    APP_ERROR_CHECK(err_code);

    // Enter main loop
    for (;;)
    {
        if (NRF_LOG_PROCESS() == false)
        {
            power_manage();
        }
    }
}


/**
 * @}
 */

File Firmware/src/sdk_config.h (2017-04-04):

#ifndef SDK_CONFIG_H
#define SDK_CONFIG_H
// <<< Use Configuration Wizard in Context Menu >>>\n
#ifdef USE_APP_CONFIG
#include "app_config.h"
#endif
// <h> nRF_BLE 

//==========================================================
// <h> SPI_CONFIGURATION - Spi configuration

//==========================================================
// <o> SPI_SCK_PIN - Pin number  <0-31> 


#ifndef SPI_SCK_PIN
#define SPI_SCK_PIN 14
#endif

// <o> SPI_MISO_PIN - Pin number  <0-31> 


#ifndef SPI_MISO_PIN
#define SPI_MISO_PIN 12
#endif

// <o> SPI_MOSI_PIN - Pin number  <0-31> 


#ifndef SPI_MOSI_PIN
#define SPI_MOSI_PIN 13
#endif

// <o> SPI_SS_PIN - Pin number  <0-31> 


#ifndef SPI_SS_PIN
#define SPI_SS_PIN 11
#endif

// <o> SPI_IRQ_PRIORITY  - Interrupt priority
 

// <i> Priorities 0,2 (nRF51) and 0,1,4,5 (nRF52) are reserved for SoftDevice
// <0=> 0 (highest) 
// <1=> 1 
// <2=> 2 
// <3=> 3 
// <4=> 4 
// <5=> 5 
// <6=> 6 
// <7=> 7 

#ifndef SPI_IRQ_PRIORITY
#define SPI_IRQ_PRIORITY 7
#endif


//==========================================================
// <q> BLE_ADVERTISING_ENABLED  - ble_advertising - Advertising module
 

#ifndef BLE_ADVERTISING_ENABLED
#define BLE_ADVERTISING_ENABLED 1
#endif

// <q> BLE_DTM_ENABLED  - ble_dtm - Module for testing RF/PHY using DTM commands
 

#ifndef BLE_DTM_ENABLED
#define BLE_DTM_ENABLED 0
#endif

// <q> BLE_RACP_ENABLED  - ble_racp - Record Access Control Point library
 

#ifndef BLE_RACP_ENABLED
#define BLE_RACP_ENABLED 0
#endif

// <q> NRF_BLE_QWR_ENABLED  - nrf_ble_qwr - Queued writes support module (prepare/execute write)
 

#ifndef NRF_BLE_QWR_ENABLED
#define NRF_BLE_QWR_ENABLED 0
#endif

// <q> PEER_MANAGER_ENABLED  - peer_manager - Peer Manager
 

#ifndef PEER_MANAGER_ENABLED
#define PEER_MANAGER_ENABLED 1
#endif

// </h> 
//==========================================================

// <h> nRF_BLE_Services 

//==========================================================
// <q> BLE_ANCS_C_ENABLED  - ble_ancs_c - Apple Notification Service Client
 

#ifndef BLE_ANCS_C_ENABLED
#define BLE_ANCS_C_ENABLED 0
#endif

// <q> BLE_ANS_C_ENABLED  - ble_ans_c - Alert Notification Service Client
 

#ifndef BLE_ANS_C_ENABLED
#define BLE_ANS_C_ENABLED 0
#endif

// <q> BLE_BAS_C_ENABLED  - ble_bas_c - Battery Service Client
 

#ifndef BLE_BAS_C_ENABLED
#define BLE_BAS_C_ENABLED 0
#endif

// <q> BLE_BAS_ENABLED  - ble_bas - Battery Service
 

#ifndef BLE_BAS_ENABLED
#define BLE_BAS_ENABLED 1
#endif

// <q> BLE_CSCS_ENABLED  - ble_cscs - Cycling Speed and Cadence Service
 

#ifndef BLE_CSCS_ENABLED
#define BLE_CSCS_ENABLED 0
#endif

// <q> BLE_CTS_C_ENABLED  - ble_cts_c - Current Time Service Client
 

#ifndef BLE_CTS_C_ENABLED
#define BLE_CTS_C_ENABLED 0
#endif

// <q> BLE_DIS_ENABLED  - ble_dis - Device Information Service
 

#ifndef BLE_DIS_ENABLED
#define BLE_DIS_ENABLED 1
#endif

// <q> BLE_GLS_ENABLED  - ble_gls - Glucose Service
 

#ifndef BLE_GLS_ENABLED
#define BLE_GLS_ENABLED 0
#endif

// <q> BLE_HIDS_ENABLED  - ble_hids - Human Interface Device Service
 

#ifndef BLE_HIDS_ENABLED
#define BLE_HIDS_ENABLED 0
#endif

// <e> BLE_HRS_C_ENABLED - ble_hrs_c - Heart Rate Service Client
//==========================================================
#ifndef BLE_HRS_C_ENABLED
#define BLE_HRS_C_ENABLED 0
#endif
#if  BLE_HRS_C_ENABLED
// <o> BLE_HRS_C_RR_INTERVALS_MAX_CNT - Maximum number of RR_INTERVALS per notification to be decoded 
#ifndef BLE_HRS_C_RR_INTERVALS_MAX_CNT
#define BLE_HRS_C_RR_INTERVALS_MAX_CNT 30
#endif

#endif //BLE_HRS_C_ENABLED
// </e>

// <q> BLE_HRS_ENABLED  - ble_hrs - Heart Rate Service
 

#ifndef BLE_HRS_ENABLED
#define BLE_HRS_ENABLED 0
#endif

// <q> BLE_HTS_ENABLED  - ble_hts - Health Thermometer Service
 

#ifndef BLE_HTS_ENABLED
#define BLE_HTS_ENABLED 0
#endif

// <q> BLE_IAS_C_ENABLED  - ble_ias_c - Immediate Alert Service Client
 

#ifndef BLE_IAS_C_ENABLED
#define BLE_IAS_C_ENABLED 0
#endif

// <q> BLE_IAS_ENABLED  - ble_ias - Immediate Alert Service
 

#ifndef BLE_IAS_ENABLED
#define BLE_IAS_ENABLED 0
#endif

// <q> BLE_LBS_C_ENABLED  - ble_lbs_c - Nordic LED Button Service Client
 

#ifndef BLE_LBS_C_ENABLED
#define BLE_LBS_C_ENABLED 0
#endif

// <q> BLE_LBS_ENABLED  - ble_lbs - LED Button Service
 

#ifndef BLE_LBS_ENABLED
#define BLE_LBS_ENABLED 0
#endif

// <q> BLE_LLS_ENABLED  - ble_lls - Link Loss Service
 

#ifndef BLE_LLS_ENABLED
#define BLE_LLS_ENABLED 0
#endif

// <q> BLE_NUS_C_ENABLED  - ble_nus_c - Nordic UART Central Service
 

#ifndef BLE_NUS_C_ENABLED
#define BLE_NUS_C_ENABLED 0
#endif

// <q> BLE_NUS_ENABLED  - ble_nus - Nordic UART Service
 

#ifndef BLE_NUS_ENABLED
#define BLE_NUS_ENABLED 0
#endif

// <q> BLE_RSCS_C_ENABLED  - ble_rscs_c - Running Speed and Cadence Client
 

#ifndef BLE_RSCS_C_ENABLED
#define BLE_RSCS_C_ENABLED 0
#endif

// <q> BLE_RSCS_ENABLED  - ble_rscs - Running Speed and Cadence Service
 

#ifndef BLE_RSCS_ENABLED
#define BLE_RSCS_ENABLED 0
#endif

// <q> BLE_TPS_ENABLED  - ble_tps - TX Power Service
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

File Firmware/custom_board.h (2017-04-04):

#ifndef BOARD_CUSTOM_H
#define BOARD_CUSTOM_H

#ifdef __cplusplus
extern "C" {
#endif

#include "nrf_gpio.h"

/**************/
/**** B201 ****/
/**************/
#define LEDS_NUMBER    2

#define LED_1          8	// LED1
#define LED_2          18	// LED2

#define LEDS_ACTIVE_STATE 1

#define LEDS_LIST { LED_1, LED_2 }

#define BSP_LED_0      LED_1
#define BSP_LED_1      LED_2

#define LEDS_INV_MASK  LEDS_MASK

#define BUTTONS_NUMBER 2

#define BUTTON_1       30	// GPS_EN
#define BUTTON_2       16	// ON/OFF
#define BUTTON_PULL    NRF_GPIO_PIN_PULLUP

#define BUTTONS_ACTIVE_STATE 0

#define BUTTONS_LIST { BUTTON_1, BUTTON_2 }

#define BSP_BUTTON_0   BUTTON_1
#define BSP_BUTTON_1   BUTTON_2

#define RX_PIN_NUMBER  5
#define TX_PIN_NUMBER  6
#define CTS_PIN_NUMBER 7
#define RTS_PIN_NUMBER 31
#define HWFC           true

#define SPIS_MISO_PIN   12  // SPI MISO signal.
#define SPIS_CSN_PIN    11  // SPI CSN signal.
#define SPIS_MOSI_PIN   13  // SPI MOSI signal.
#define SPIS_SCK_PIN    14  // SPI SCK signal.

#define SPIM0_SCK_PIN   14  // SPI clock GPIO pin number.
#define SPIM0_MOSI_PIN  13  // SPI Master Out Slave In GPIO pin number.
#define SPIM0_MISO_PIN  12  // SPI Master In Slave Out GPIO pin number.
#define SPIM0_SS_PIN    11  // SPI Slave Select GPIO pin number.

#define ARDUINO_SCL_PIN 3  // SCL signal pin
#define ARDUINO_SDA_PIN 2  // SDA signal pin

// Low frequency clock source to be used by the SoftDevice
#define NRF_CLOCK_LFCLKSRC      {.source        = NRF_CLOCK_LF_SRC_XTAL,            \
                                 .rc_ctiv       = 0,                                \
                                 .rc_temp_ctiv  = 0,                                \
                                 .xtal_accuracy = NRF_CLOCK_LF_XTAL_ACCURACY_20_PPM}

#ifdef __cplusplus
}
#endif

#endif // BOARD_CUSTOM_H

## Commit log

2017-03-29 B201 package push
    [B201-Prodat_B112_20170322.xlsx, B201_NINA-B112BoM_170322.xlsx, NINA_B201_170322.DSN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]
2017-04-06 Version 0.1.4 - Bug fix lng parsing
    [main.c]
2017-12-15 Restructured hw files.
    [B201-Prodat_B112_20170322.xlsx, NINA_B201_170322.DSN, NINA_B201_170322.brd]
